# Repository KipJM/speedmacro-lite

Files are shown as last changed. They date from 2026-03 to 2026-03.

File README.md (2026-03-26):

# speedmacro-lite
**A small macropad with a similar key layout to the Davinci Resolve speed editor.**

Includes a rotary encoder (no click) and an OLED screen.

The key layout is designed to mimic a combination of the left and middle part of a Davinci Resolve speed editor, with two 1.5u "in" "out" point buttons at the top and a long 3u "play/pause" button at the bottom, with stabilizers. ergobleds are included with each key, plus a row of additional lighting is added at the top.

# CAD Model

The case is made up of two parts, the bottom carrier and the top plate. M3 16mm bolts are designed to thread through the entire sandwich assembly and act as adjustable feet for the macropad.

# Schematics
This macro pad uses a matrix wiring model, however caution that the electrical arrangement of switches do not match the actual physical location of the switches, because of the 2-3-3-1 switch layout this board uses.






## Firmware
SpeedMacro lite uses QMK firmware, but feel free to use other firmware platforms.
A minimal sample firmware build is provided.

## Bill of Materials
- 9x Cherry MX Switches
- 9x Cherry MX hotswap sockets
- 6x 1u DSA keycaps
- 2x 1.5u DSA keycaps
- 1x 3u DSA keycap (with stabs)
- 1x 3u stabs
- 4x M3x16mm SHCS Bolts
- 9x 1N4148 DO-35 Diodes
- 16x SK6812 MINI-E LEDs
- (optional) 4x M3x5mx4mm heatset inserts
- 1x 0.91in OLED Display
- 1x EC11 Rotary Encoder
- 1x 3D-printed case (2 parts)
- 1x Custom Printed Circuit Board
- 1x SEEED Studio XIAO RP2040

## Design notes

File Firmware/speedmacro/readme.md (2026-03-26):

# speedmacro

*A 9-key macropad with a similar key layout to Davinci Resolve speed editor.*

* Keyboard Maintainer: [Kip](https://github.com/KipJM)
* Hardware Supported: *Speedmacro*
* Hardware Availability: *[Speedmacro](https://github.com/KipJM/speedmacro)*

Make example for this keyboard (after setting up your build environment):

    make speedmacro:default

Flashing example for this keyboard:

    make speedmacro:default:flash

See the [build environment setup](https://docs.qmk.fm/#/getting_started_build_tools) and the [make instructions](https://docs.qmk.fm/#/getting_started_make_guide) for more information. Brand new to QMK? Start with our [Complete Newbs Guide](https://docs.qmk.fm/#/newbs).

## Bootloader

Enter the bootloader in 3 ways:

* **Bootmagic reset**: Hold down the key at (0,0) in the matrix (usually the top left key or Escape) and plug in the keyboard
* **Physical reset button**: Briefly press the button on the back of the PCB - some may have pads you must short instead
* **Keycode in layout**: Press the key mapped to `QK_BOOT` if it is available

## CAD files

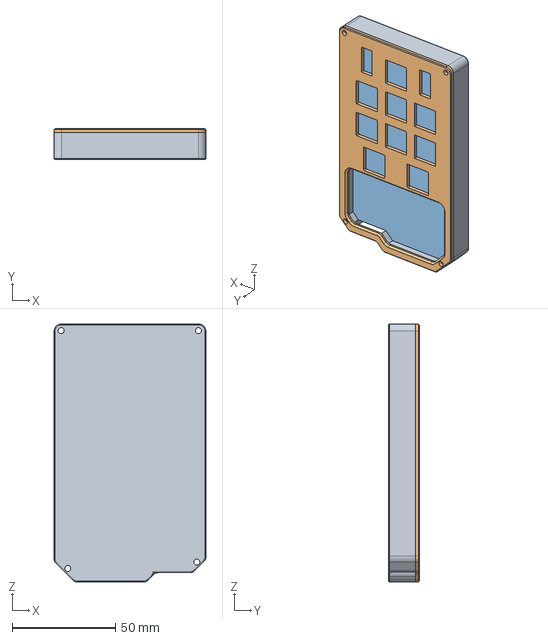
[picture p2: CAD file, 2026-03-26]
CAD/SpeedMacro.step
73.5 x 15.0 x 125.0 mm
Case Bottom
Case Top

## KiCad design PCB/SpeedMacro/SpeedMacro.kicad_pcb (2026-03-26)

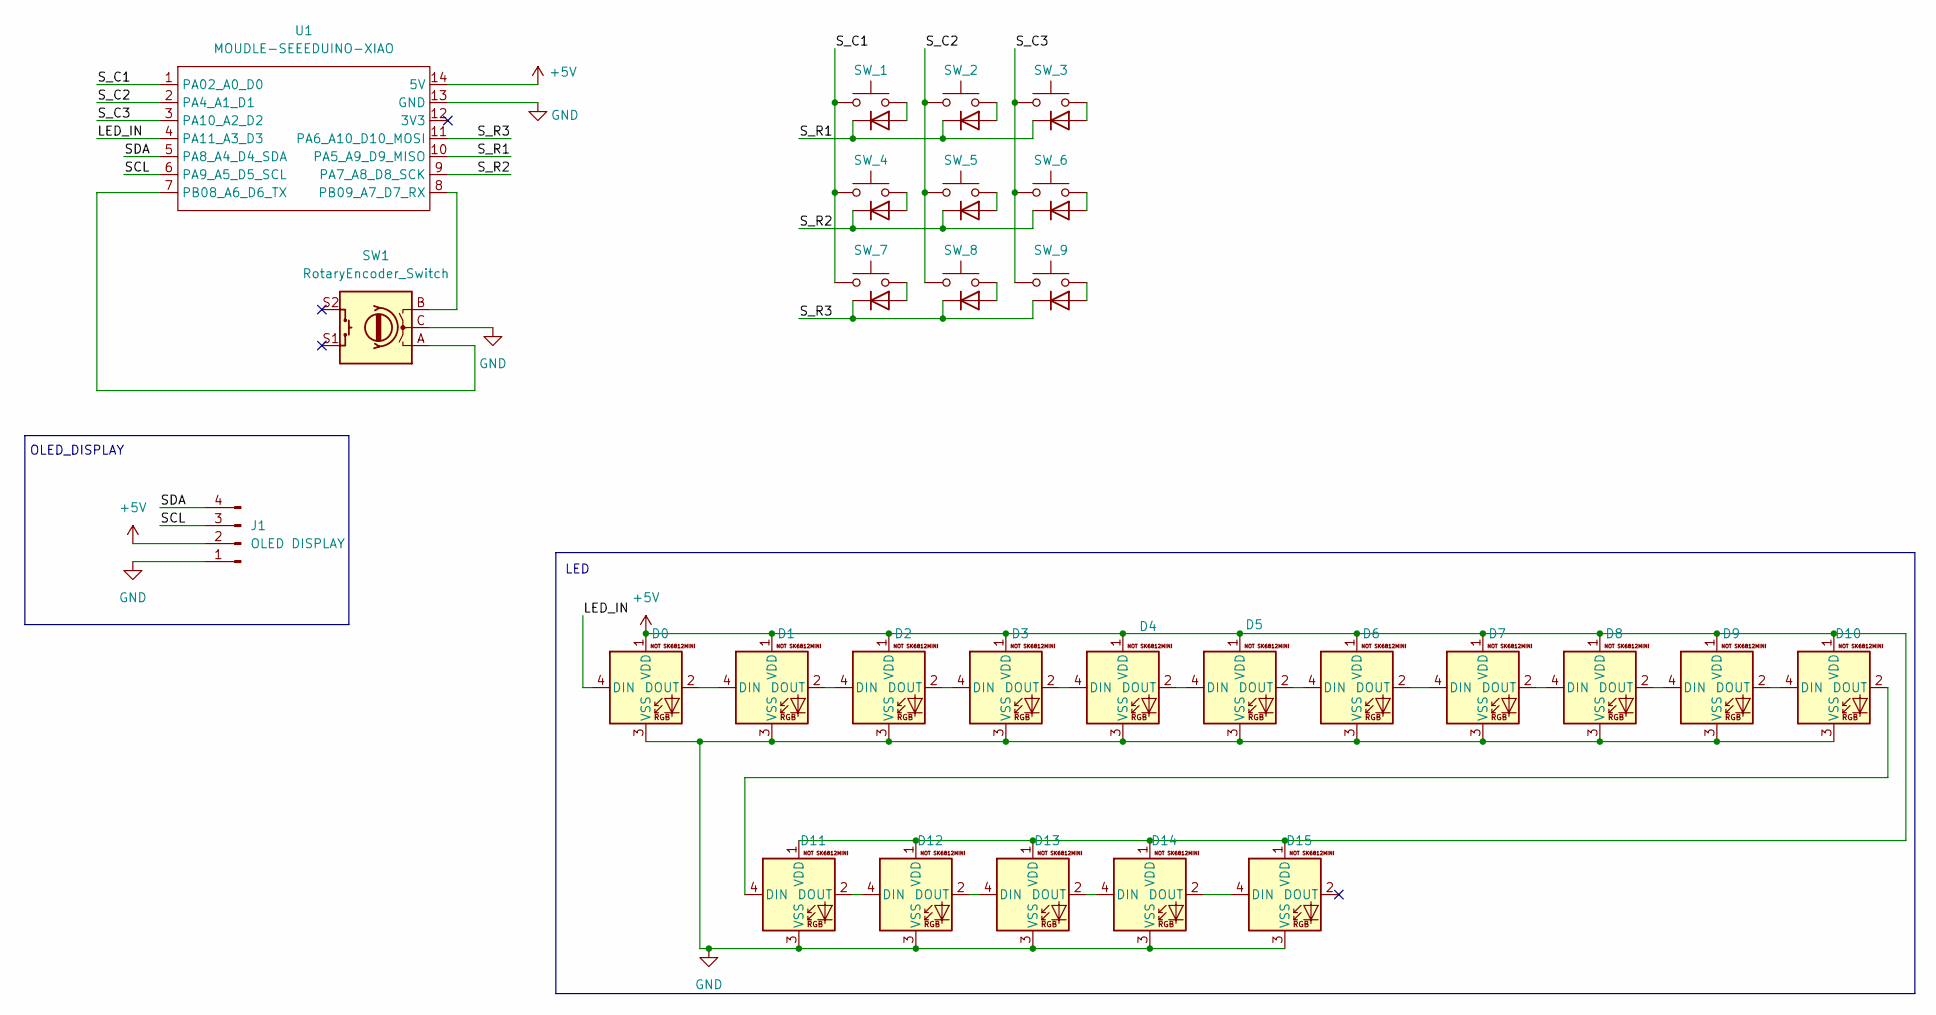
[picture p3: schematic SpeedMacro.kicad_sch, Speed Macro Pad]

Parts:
D0, D1, D2, D3, D4, D5, D6, D7, D8, D9, D10, D11, D12, D13, D14, D15: SK6812MINI-E; SK6812MINI-E_fixed
D16, D17, D18, D19, D20, D22, D23, D24, D28: 1N4148; D_DO-35_SOD27_P7.62mm_Horizontal
J1: OLED DISPLAY; PinHeader_1x04_P2.54mm_Vertical
SW1: RotaryEncoder_Switch; RotaryEncoder_Alps_EC11E-Switch_Vertical_H20mm
SW_1, SW_2, SW_3, SW_4, SW_5, SW_6, SW_7, SW_8, SW_9: SW_Push; SW_Hotswap_Kailh_MX_1.00u
U1: MOUDLE-SEEEDUINO-XIAO; XIAO-Generic-Hybrid-14P-2.54-21X17.8MM

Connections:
+5V: D0.1 (VDD), D1.1 (VDD), D2.1 (VDD), D3.1 (VDD), D4.1 (VDD), D5.1 (VDD), D6.1 (VDD), D7.1 (VDD), D8.1 (VDD), D9.1 (VDD), D10.1 (VDD), D11.1 (VDD), D12.1 (VDD), D13.1 (VDD), D14.1 (VDD), D15.1 (VDD), J1.2, U1.14 (5V)
/LED_IN: D0.4 (DIN), U1.4 (PA11_A3_D3)
/SCL: J1.3, U1.6 (PA9_A5_D5_SCL)
/SDA: J1.4, U1.5 (PA8_A4_D4_SDA)
/S_C1: SW_1.1, SW_4.1, SW_7.1, U1.1 (PA02_A0_D0)
/S_C2: SW_2.1, SW_5.1, SW_8.1, U1.2 (PA4_A1_D1)
/S_C3: SW_3.1, SW_6.1, SW_9.1, U1.3 (PA10_A2_D2)
/S_R1: D16.1 (K), D17.1 (K), D19.1 (K), U1.10 (PA5_A9_D9_MISO)
/S_R2: D18.1 (K), D20.1 (K), D23.1 (K), U1.9 (PA7_A8_D8_SCK)
/S_R3: D22.1 (K), D24.1 (K), D28.1 (K), U1.11 (PA6_A10_D10_MOSI)
GND: D0.3 (VSS), D1.3 (VSS), D2.3 (VSS), D3.3 (VSS), D4.3 (VSS), D5.3 (VSS), D6.3 (VSS), D7.3 (VSS), D8.3 (VSS), D9.3 (VSS), D10.3 (VSS), D11.3 (VSS), D12.3 (VSS), D13.3 (VSS), D14.3 (VSS), D15.3 (VSS), J1.1, SW1.C, U1.13 (GND)
unnamed: D0.2 (DOUT), D1.4 (DIN)
unnamed: D1.2 (DOUT), D2.4 (DIN)
unnamed: D2.2 (DOUT), D3.4 (DIN)
unnamed: D3.2 (DOUT), D4.4 (DIN)
unnamed: D4.2 (DOUT), D5.4 (DIN)
unnamed: D5.2 (DOUT), D6.4 (DIN)
unnamed: D6.2 (DOUT), D7.4 (DIN)
unnamed: D7.2 (DOUT), D8.4 (DIN)
unnamed: D8.2 (DOUT), D9.4 (DIN)
unnamed: D9.2 (DOUT), D10.4 (DIN)
unnamed: D10.2 (DOUT), D11.4 (DIN)
unnamed: D11.2 (DOUT), D12.4 (DIN)
unnamed: D12.2 (DOUT), D13.4 (DIN)
unnamed: D13.2 (DOUT), D14.4 (DIN)
unnamed: D14.2 (DOUT), D15.4 (DIN)
unnamed: D16.2 (A), SW_1.2
unnamed: D17.2 (A), SW_3.2
unnamed: D18.2 (A), SW_4.2
unnamed: D19.2 (A), SW_2.2
unnamed: D20.2 (A), SW_6.2
unnamed: D22.2 (A), SW_7.2
unnamed: D23.2 (A), SW_5.2
unnamed: D24.2 (A), SW_9.2
unnamed: D28.2 (A), SW_8.2
unnamed: SW1.A, U1.7 (PB08_A6_D6_TX)
unnamed: SW1.B, U1.8 (PB09_A7_D7_RX)

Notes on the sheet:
LED
OLED_DISPLAY

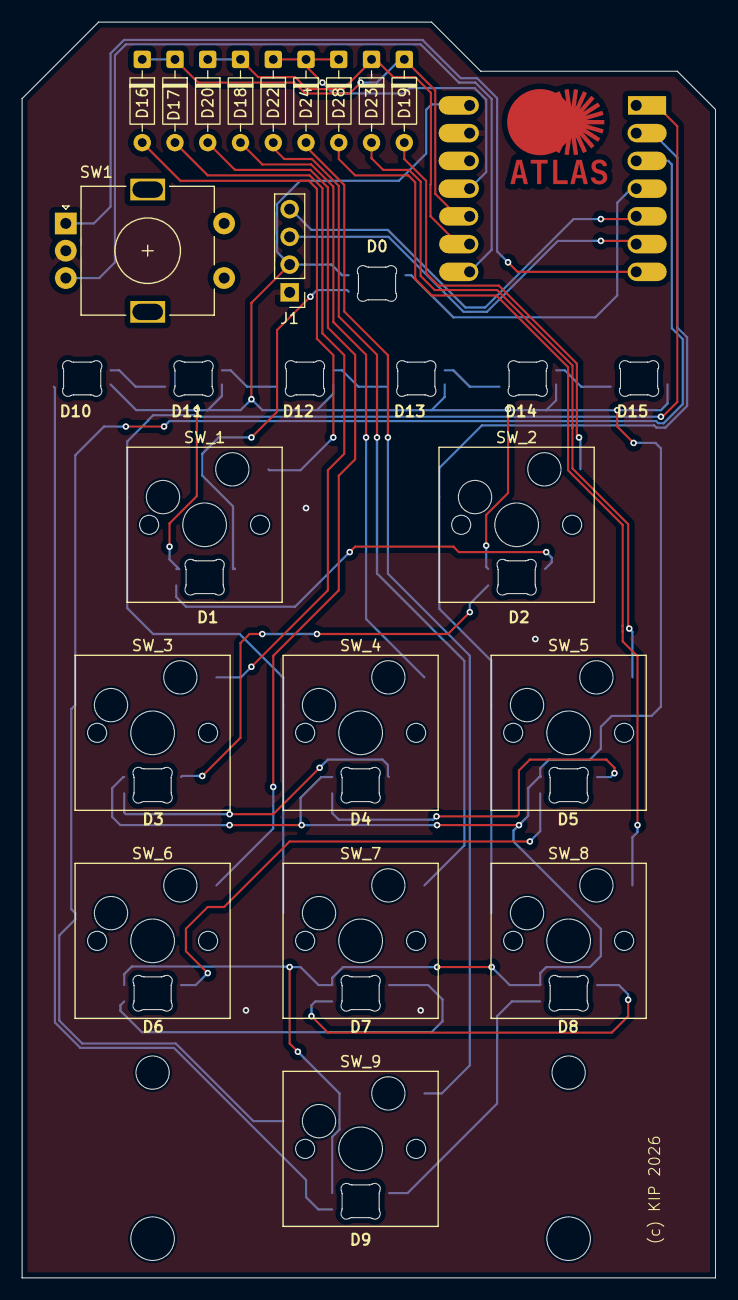
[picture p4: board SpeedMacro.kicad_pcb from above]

Board: 2 copper layers, 63.5 x 115.0 mm, 38 parts (1 on the bottom side), 37 nets.

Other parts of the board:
LOGO: LOGO
